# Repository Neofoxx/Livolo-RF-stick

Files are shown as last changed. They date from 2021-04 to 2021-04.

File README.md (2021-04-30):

# LIVOLO-RF-Stick
A USB dongle for controlling Livolo RF switches

#### Finished product
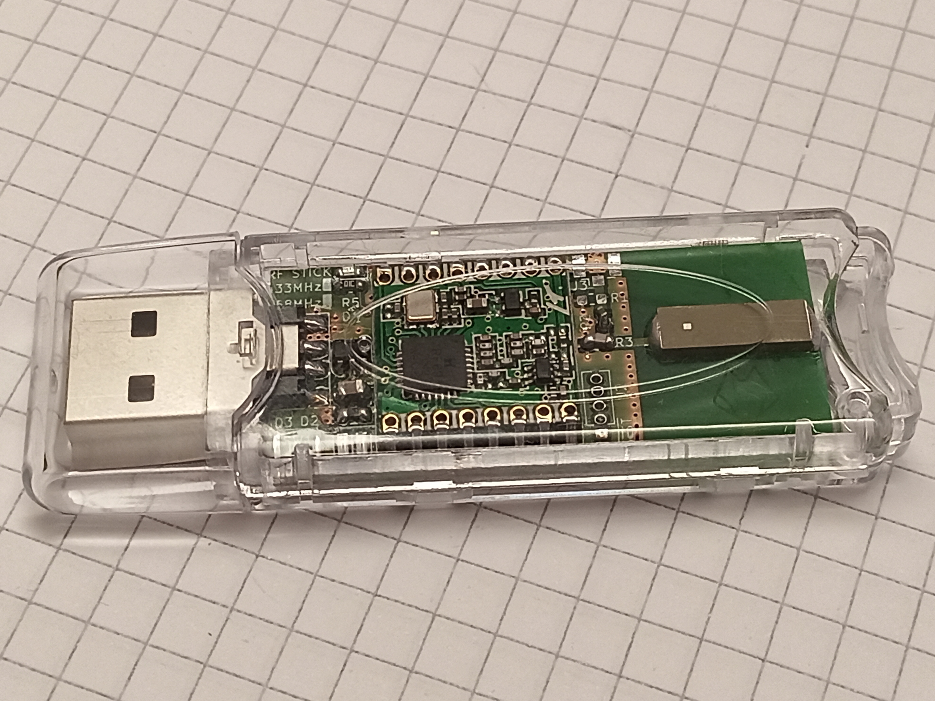
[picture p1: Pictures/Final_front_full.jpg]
Front view of finished product

*Front view of finished product*

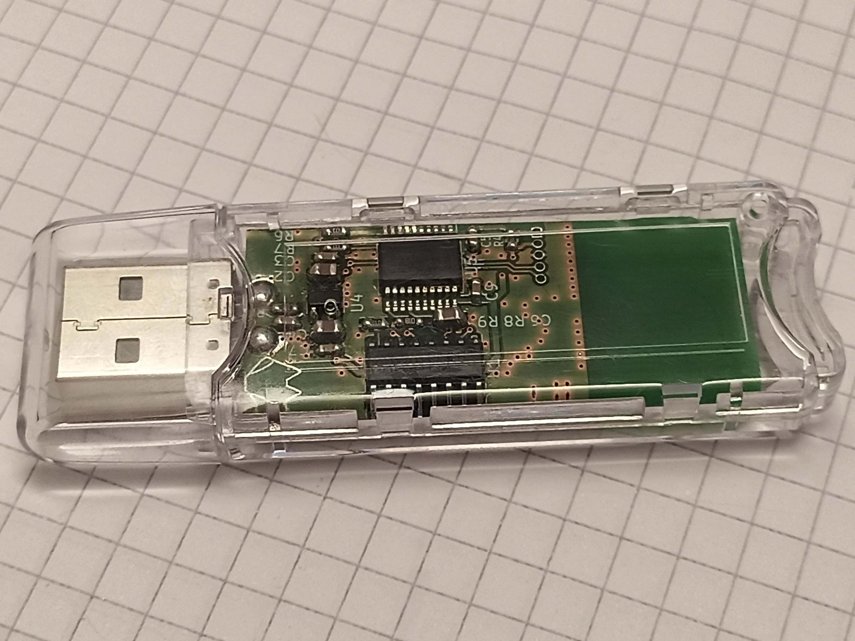
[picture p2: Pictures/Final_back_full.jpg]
Back view of finished product

*Back view of finished product*

#### PCB board view
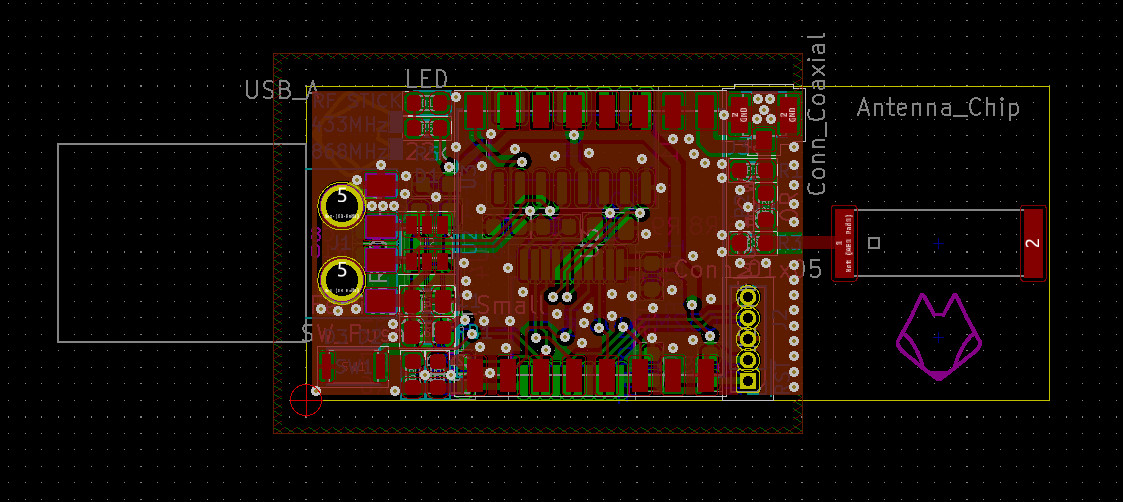
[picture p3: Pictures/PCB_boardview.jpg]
PCB board view

*PCB board view*

## Description

This is a simple dongle for controling Livolo brand RF switched.
It is based around the following components:
- [PIC32MM0064GPL020s](https://www.microchip.com/wwwproducts/en/PIC32MM0064GPL020) microcontroller
- [RFM69](https://www.hoperf.com/modules/rf_transceiver/RFM69HCW.html) module
- CH340G USB-serial converter
- ABRACON [ACAG1204-433-T](https://abracon.com/datasheets/ACAG1204-433-T.pdf) ceramic antenna
- Multicomp [MCG1901](https://uk.farnell.com/multicomp/mcg1901/box-usb-plug-in-clear-polycarbonate/dp/1603603) plastic housing (Wifi dongle style)

#### Performance
Performance is about on-par with the official handheld remote.
Antenna tuning is 72nH in series with antenna, 1pF in parallel with antenna.

#### Extra info

A longer writeup can be found [here](https://neofoxx.com/post-4.html).

## Usage example

Connect to the dongle at 115200bps, 8N1.
Send commands like "COMMAND [...]\n". Commands can be either lower or uppercase.

A help command is implemented, and will printout this:
```
RF stick, for controlling Livolo switches␊
Commands:␊
HELP - Print this help
SCAN - Perform an RSSI scan of a wider area
DEBUG - Print out some diagnostic data
SNIFF [Minimum RSSI] [Timeout] - Sniff for Livolo packets.
-> RSSI should be [-115 to 0]. In practice, use -80, maybe -90 for really weak signals
-> Timeout is in miliseconds. You can put 0 for no timeout. You can always end by sending \n
TRANSMIT [Remote ID] [Keycode] [Number of repeats] - Send a packet many times
-> Remote ID is a 16-bit unsigned number
-> Keycode is a 6-bit unsigned number
-> Number of packets can be [1 to 1000]. Each one takes 8ms, fyi.
----> THIS DOES NOT VERIFY IF YOU DATA IS CORRECT. YOU HAVE TO MAKE SURE THAT YOU HAVE THE RIGHT NUMBER OF 1s!
```

Take special care when sending packets, as the switches are fussy about how many you send -> they **react differently** to how many packets you send.
- ON/OFF commands - 25 to 30 packets is kinda the ideal. If you send more than 50, weird things start happening (lights turning ON and then back OFF or vice versa)
- DIMMING commands - a minimum of 20 packets works reliably. It sometimes works with less, but it's not recommended. This means you can dim the light on in increments, by sending >=20 packets for each UP increment.

Each button on a remote send two different key codes, depending on how you press a button.
- SHORT press - send those 25-30 packets, with a keycode **X**
- LONG press - continues sending packets until release, with keycode **Y**. Used for dimming

To synchronize/bind a key, you **MUST** send the **ON/OFF** command (**SHORT press**). After you put the switch into its "synchronize/learning/binding" mode of course. The switch should respond with a single **beep** when button is bound (at least on my test switch)-

To unbind a key, you *can* send the the **ON/OFF** sequence twice (or just a longer packet), when the switch is in its "synchronize/learning/binding" mode. The switch should responded with two **beeps** when it unbinds (again, works on my test unit).
This also works with a normal remote, if you double-tap a key, though I couldn't find this functionality in the included mini-manual.

#### TLDR
1. Send "SNIFF -90 20", so get the REMOTE_ID and Keycode_ID from your existing remote
2. Send "TRANSMIT [REMOTE_ID] [Keycode_ID] 25" for ON/OFF commands
3. Send "TRANSMIT [REMOTE_ID] [Keycode_ID] [DO_YOUR_OWN_MATH]" for dimming commands. Time sending packets = (8ms * number_of_packets), or flipped, number_of_packets = total_time_in_ms / 8.

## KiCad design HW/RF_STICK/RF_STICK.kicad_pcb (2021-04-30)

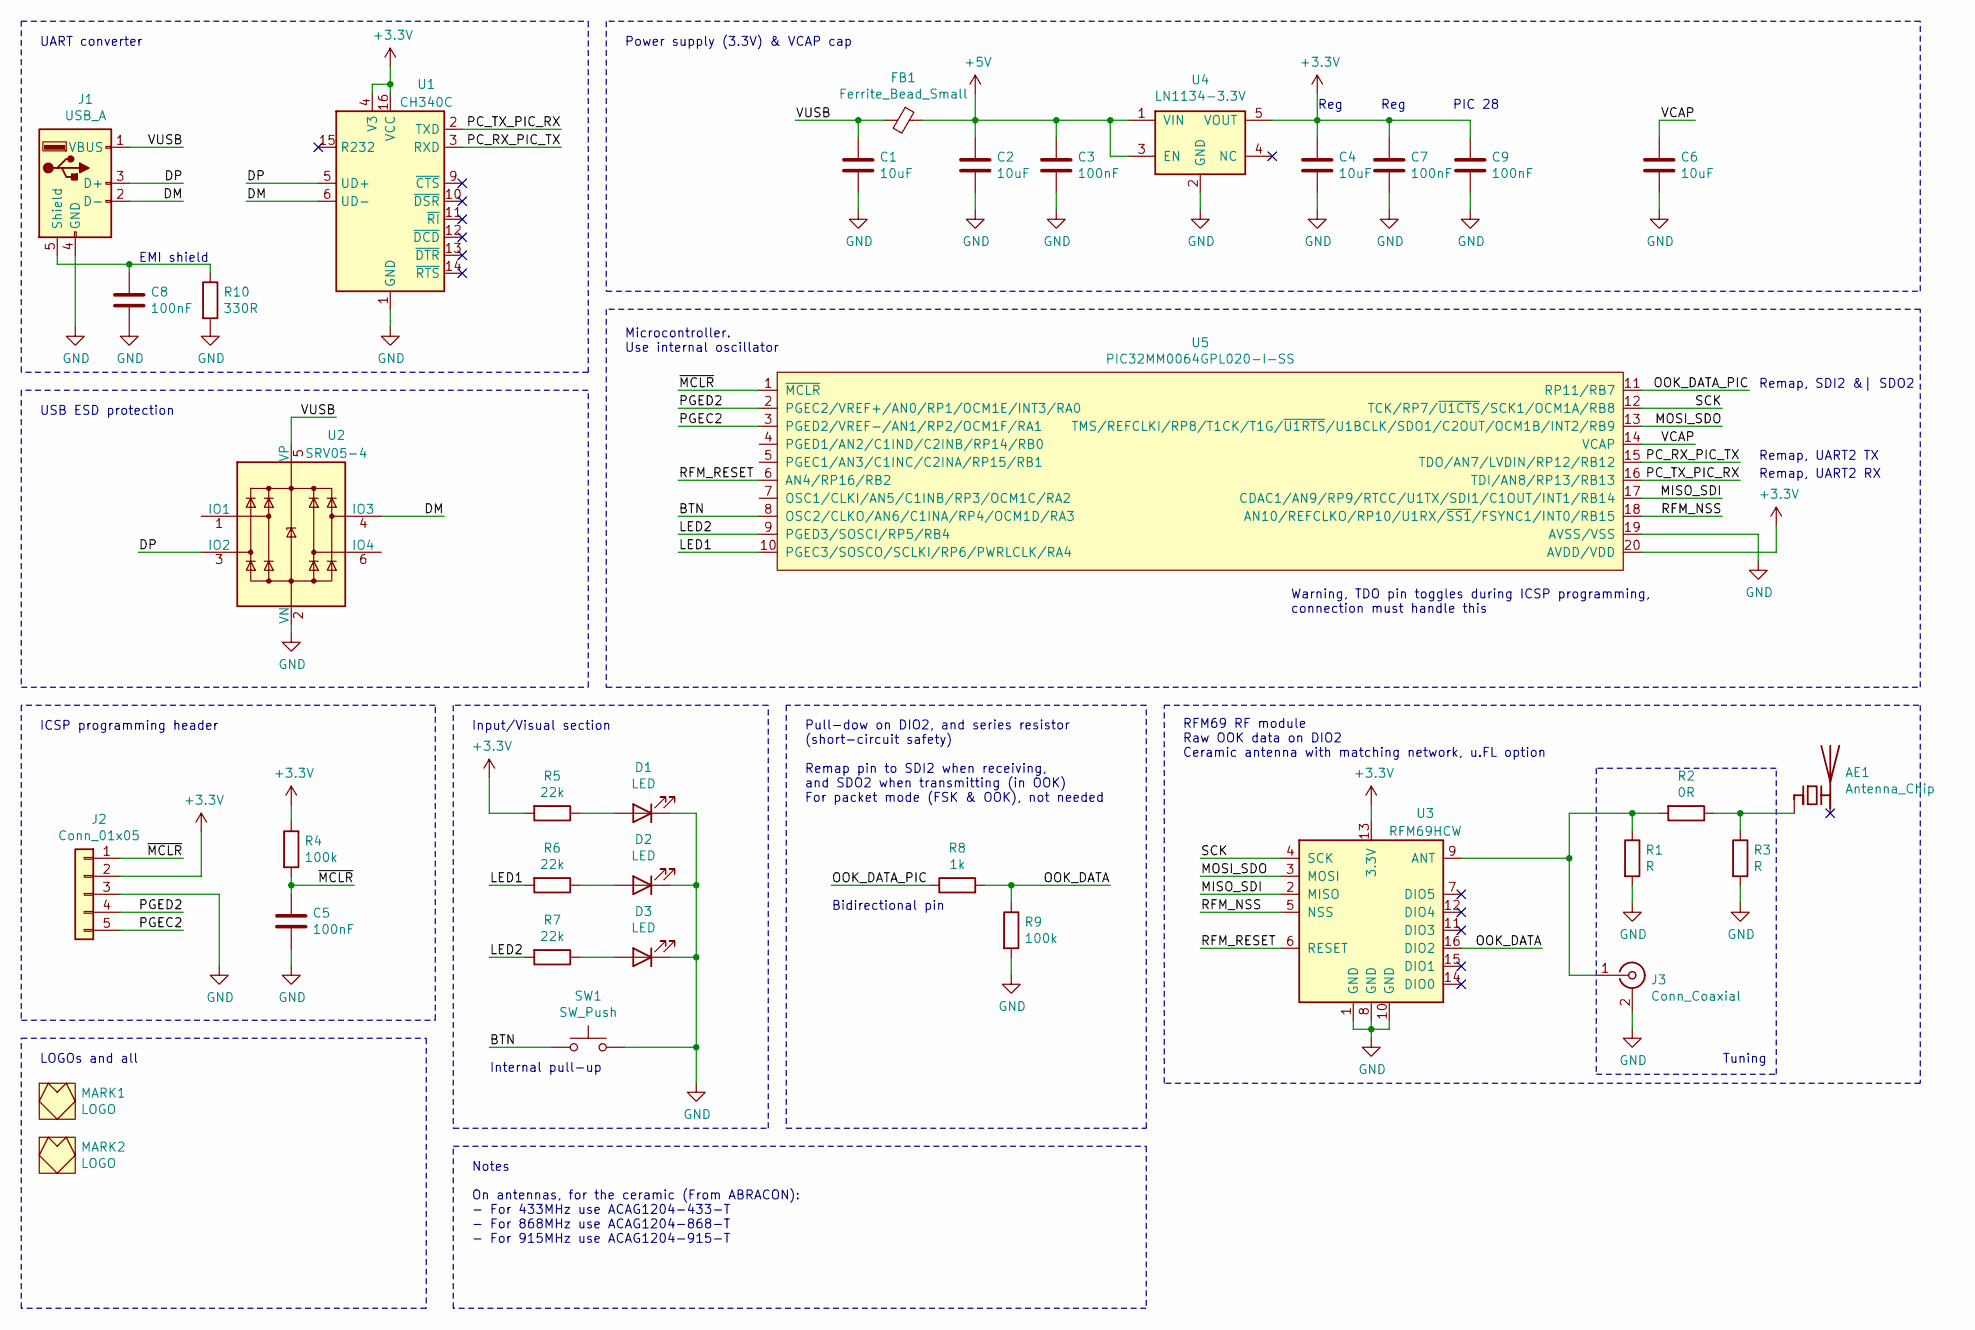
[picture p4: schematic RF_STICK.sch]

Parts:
AE1: Antenna_Chip; ACAG1204-433-T
C1, C2, C4, C6: 10uF; C_0805_2012Metric
C3, C5, C7, C8, C9: 100nF; C_0603_1608Metric
D1, D2, D3: LED; LED_0603_1608Metric
FB1: Ferrite_Bead_Small; L_0805_2012Metric
J1: USB_A; USB_A_PCB
J2: Conn_01x05; PinHeader_1x05_P1.27mm_Vertical
J3: Conn_Coaxial; U.FL_Hirose_U.FL-R-SMT-1_Vertical
MARK1, MARK2: LOGO; FOX_LOGO_MASK
R1, R3: R; R_0603_1608Metric
R2: 0R; R_0603_1608Metric
R4, R9: 100k; R_0603_1608Metric
R5, R6, R7: 22k; R_0603_1608Metric
R8: 1k; R_0603_1608Metric
R10: 330R; R_0603_1608Metric
SW1: SW_Push; SW_SPST_CK_KXT3
U1: CH340C; SOIC-16_3.9x9.9mm_P1.27mm
U2: SRV05-4; SOT-23-6
U3: RFM69HCW; HOPERF_RFM9XW_SMD
U4: LN1134-3.3V; SOT-23-5
U5: PIC32MM0064GPL020-I-SS; SSOP-20_5.3x7.2mm_P0.65mm_MOD

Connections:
+3V3: C4.1, C7.1, C9.1, J2.2, R4.1, R5.2, U1.4 (V3), U1.16 (VCC), U3.13 (3.3V), U4.5 (VOUT), U5.20 (AVDD/VDD)
+5V: C2.1, C3.1, FB1.1, U4.1 (VIN), U4.3 (EN)
/BTN: SW1.1, U5.8 (OSC2/CLKO/AN6/C1INA/RP4/OCM1D/RA3)
/DM: J1.2 (D-), U1.6 (UD-), U2.4 (IO3)
/DP: J1.3 (D+), U1.5 (UD+), U2.3 (IO2)
/LED1: R6.2, U5.10 (PGEC3/SOSCO/SCLKI/RP6/PWRLCLK/RA4)
/LED2: R7.2, U5.9 (PGED3/SOSCI/RP5/RB4)
/MISO_SDI: U3.2 (MISO), U5.17 (CDAC1/AN9/RP9/RTCC/U1TX/SDI1/C1OUT/INT1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)
/MOSI_SDO: U3.3 (MOSI), U5.13 (TMS/REFCLKI/RP8/T1CK/T1G/~U1RTS~/U1BCLK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)
/OOK_DATA: R8.2, R9.1, U3.16 (DIO2)
/OOK_DATA_PIC: R8.1, U5.11 (RP11/RB7)
/PC_RX_PIC_TX: U1.3 (RXD), U5.15 (TDO/AN7/LVDIN/RP12/RB12)
/PC_TX_PIC_RX: U1.2 (TXD), U5.16 (TDI/AN8/RP13/RB13)
/PGEC2: J2.5, U5.3 (PGED2/VREF-/AN1/RP2/OCM1F/RA1)
/PGED2: J2.4, U5.2 (PGEC2/VREF+/AN0/RP1/OCM1E/INT3/RA0)
/RFM_NSS: U3.5 (NSS), U5.18 (AN10/REFCLKO/RP10/U1RX/~SS1~/FSYNC1/INT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)
/RFM_RESET: U3.6 (RESET), U5.6 (AN4/RP16/RB2)
/SCK: U3.4 (SCK), U5.12 (TCK/RP7/~U1CTS~/SCK1/OCM1A/RB8)
/VCAP: C6.1, U5.14 (VCAP)
/VUSB: C1.1, FB1.2, J1.1 (VBUS), U2.5 (VP)
/~MCLR~: C5.1, J2.1, R4.2, U5.1 (~MCLR~)
GND: C1.2, C2.2, C3.2, C4.2, C5.2, C6.2, C7.2, C8.2, C9.2, D1.1 (K), D2.1 (K), D3.1 (K), J1.4 (GND), J2.3, J3.2 (Ext), R1.2, R3.2, R9.2, R10.2, SW1.2, U1.1 (GND), U2.2 (VN), U3.1 (GND), U3.8 (GND), U3.10 (GND), U4.2 (GND), U5.19 (AVSS/VSS)
unnamed: AE1.1 (FEED), R2.1, R3.1
unnamed: C8.1, J1.5 (Shield), R10.1
unnamed: D1.2 (A), R5.1
unnamed: D2.2 (A), R6.1
unnamed: D3.2 (A), R7.1
unnamed: J3.1 (In), R1.1, R2.2, U3.9 (ANT)

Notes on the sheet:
Reg
PIC 28
Remap, UART2 TX
Remap, SDI2 &| SDO2
Remap, UART2 RX
UART converter
USB ESD protection
Microcontroller. Use internal oscillator
Power supply (3.3V) & VCAP cap
Bidirectional pin
Internal pull-up
ICSP programming header
Input/Visual section
Tuning
RFM69 RF module Raw OOK data on DIO2 Ceramic antenna with matching network, u.FL option
Pull-dow on DIO2, and series resistor (short-circuit safety) Remap pin to SDI2 when receiving, and SDO2 when transmitting (in OOK) For packet mode (FSK & OOK), not needed
LOGOs and all
Notes
On antennas, for the ceramic (From ABRACON): - For 433MHz use ACAG1204-433-T - For 868MHz use ACAG1204-868-T - For 915MHz use ACAG1204-915-T
Warning, TDO pin toggles during ICSP programming, connection must handle this
EMI shield

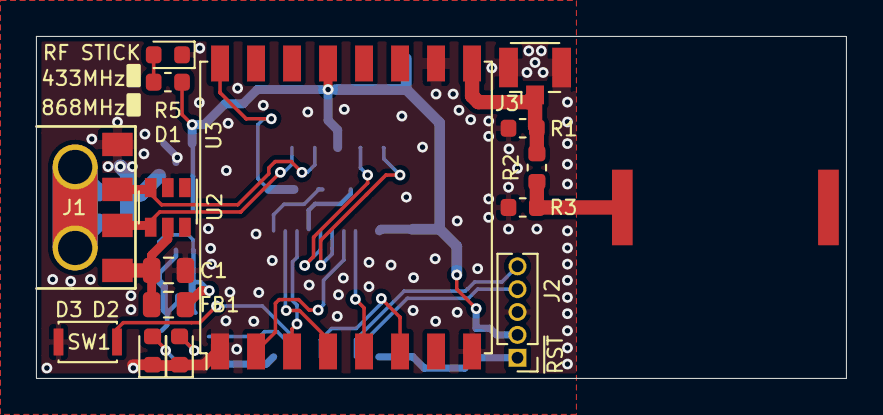
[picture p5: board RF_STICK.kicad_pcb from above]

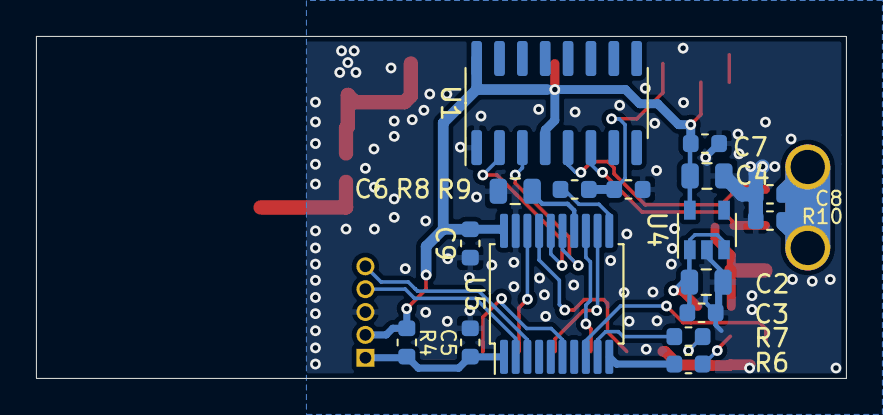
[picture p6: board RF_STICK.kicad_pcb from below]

Board: 2 copper layers, 45.0 x 19.0 mm, 35 parts (18 on the bottom side), 28 nets.

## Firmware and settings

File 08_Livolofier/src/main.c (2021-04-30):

#include <p32xxxx.h>    // Always in first place to avoid conflict with const.h -> this includes xc.h
#include <const.h>      // MIPS32
#include <inttypes.h>
#include <string.h>
#include <stdio.h>
#include <newlib.h>
#include <errno.h>
#include <stdbool.h>

// Drivers for HW
#include <configBits.h>
#include <GPIODrv.h>
#include <UARTDrv.h>
#include <SPIDrv.h>
#include <BTN.h>
#include <LED.h>
#include <COMMS.h>
#include <helper.h>
#include <RFM69.h>


// These numbers are for a baud of 57142bps.
#define LIVOLO_PREAMBLE_LEN_MIN	(32-2)
#define LIVOLO_PREAMBLE_LEN_MAX	(32+2)
#define LIVOLO_ONE_LEN_MIN	(19-2)
#define LIVOLO_ONE_LEN_MAX	(19+2)
#define LIVOLO_ZERO_LEN_MIN	(9-2)
#define LIVOLO_ZERO_LEN_MAX	(9+2)


char tempArray[512];
uint32_t lengthArray = 0;


void simpleDelay(unsigned int noOfLoops){
    unsigned int i = 0;
    while (i<noOfLoops){
        i++;
        asm("nop");
    }
}

void MIPS32 INTEnableSystemMultiVectoredInt(void)
{
    uint32_t val;

    // set the CP0 cause IV bit high
    asm volatile("mfc0   %0,$13" : "=r"(val));
    val |= 0x00800000;
    asm volatile("mtc0   %0,$13" : "+r"(val));

    INTCONSET = _INTCON_MVEC_MASK;

    // set the CP0 status IE bit high to turn on interrupts
    //INTEnableInterrupts();
	asm("ei");
}


void setup(){

	


	SYSKEY = 0x00000000;      // force lock
	SYSKEY = 0xAA996655;      // unlock
	SYSKEY = 0x556699AA; 

	SPLLCON = (0b000 << 24)	// PLLODIV = PLL divide-by-1, so we get 24MHZ from 24MHz
		| (0b0000001 << 16)		// PLLMULT = x3, so 8MHz * 3 = 24MHz
		| (0b1 << 7);			// FRC is selected as input to PLL


//	SPLLCON = (0b010 << 24)	// PLLODIV = PLL divide-by-4, so we get 24MHZ from 96MHz
//	| (0b0000101 << 16)		// PLLMULT = x12, so 8MHz * 12 = 96MHz
//	| (0b1 << 7);			// FRC is selected as input to PLL


	simpleDelay(1000);


	OSCCONbits.NOSC = 1;	// Switch to SPLL
	
	OSCCONSET = 1;			// Sets the OSWEN bit, that forces a change to news settings in NOSC
	
	SYSKEY = 0x00000000;      // force lock

	simpleDelay(100000);

	
	LED_init();
	BTN_init();
	UARTDrv_Init(115200);
	
	
	
	SPIDrv_Init(1000000, 1, 0, 0, SPI_MODE_NORMAL);	// 1MHz, CKE = 1, CKP = 0, SMP = 0, normal SPI mode.
	RFM69_Init();
	
	
	// Enable interrupts
//	INTEnableSystemMultiVectoredInt();
	
	//	_CP0_BIS_CAUSE(_CP0_CAUSE_IV_MASK);

	// Enable multi-vectored mode


	// set the CP0 status IE bit high to turn on interrupts
	//INTEnableInterrupts();
	//asm("ei");	// Compiler handles this, but should be same as _CP0_BIS_STATUS(_CP0_STATUS_IE_MASK)

	// As per datasheet
	unsigned int temp_CP0;
	asm volatile("di"); 
	asm volatile("ehb");
	temp_CP0 = _CP0_GET_CAUSE();
	temp_CP0 |= 0x00800000;
	_CP0_SET_CAUSE(temp_CP0);
	INTCONSET = _INTCON_MVEC_MASK;
	
	asm volatile("ei"); 
}

void rssiSniffer(){
	// Try to roll through frequencies, get RSSI.
	uint32_t startFreq = 430000000;
	uint32_t stopFreq = 435000000;
	uint32_t step = 10000;
	int16_t rssiCurr = -128;
	int16_t rssiTemp = -128;
	uint32_t counter = 0;
	uint32_t numCounts = 10;

	int16_t maxRSSI = -128;
	int32_t maxFreq = 0;
	
	LED_setGreen(1);

	for (; startFreq <= stopFreq; startFreq = startFreq + step){
		rssiCurr = -128;
		rssiTemp = -128;
		RFM69_SetRfCarrierFreq(startFreq);
		for (counter = 0; counter < numCounts; counter++){
			rssiTemp = RFM69_GetRSSI();
			if (rssiTemp > rssiCurr){
				rssiCurr = rssiTemp;
			}
		}
		
		if (rssiCurr > maxRSSI){
			maxRSSI = rssiCurr;
			maxFreq = startFreq;
		}
		
		lengthArray = sprintf(tempArray, "RSSI @ %ldkHz is %ddBm\n", startFreq/1000, rssiCurr);
		UARTDrv_SendBlocking((uint8_t *) tempArray, lengthArray);    
		
				
	}

	lengthArray = sprintf(tempArray, "Peak RSSI was %ddBm @ %ldkHz\n", maxRSSI, maxFreq/1000);
	UARTDrv_SendBlocking((uint8_t *) tempArray, lengthArray);   
	
	LED_setGreen(0);


	RFM69_Init();	// Need to set back to proper frequency, and this is the quickest.
}

void tryCapture(int16_t time, int16_t minRssi){

	uint32_t toRun = true;

	uint32_t startTime = _CP0_GET_COUNT();
	uint32_t totalCount = (((uint64_t)FCLK/(uint64_t)2) * (uint64_t)time) / 1000;	

	LED_setGreen(1);

	lengthArray = sprintf(tempArray, "Packet Capture procedure. Waiting for RSSI >= %ddBm\n", minRssi);
	UARTDrv_SendBlocking((uint8_t *) tempArray, lengthArray);

	// Perform for x seconds
	while(toRun){

		int16_t tempRssi = RFM69_GetRSSI();

		if (tempRssi >= minRssi){
			lengthArray = sprintf(tempArray, "RSSI is good (%ddBm), proceeding\n", tempRssi);
			UARTDrv_SendBlocking((uint8_t *) tempArray, lengthArray);	
			
			SPIDrv_Init(57142, 1, 0, 0, SPI_MODE_RX_OTHER_SDI);
			
			// One packet is 8ms, or 57B. Double to be sure to get something, +%
			uint8_t suggestiveData[128] = {0};
			SPIDrv_SendReceiveBlocking(suggestiveData, suggestiveData, 128);
			
			/*
			uint32_t counter = 0;
			int8_t bitCounter = 0;
			lengthArray = 0;
			for (counter = 0; counter<128; counter++){
				for (bitCounter = 7; bitCounter>0; bitCounter--){
					lengthArray = lengthArray + sprintf(&tempArray[lengthArray], "%d", (suggestiveData[counter] & (1<<bitCounter)) ? 1 : 0);
				}
				//lengthArray = lengthArray + sprintf(&tempArray[lengthArray], "%02x", suggestiveData[counter]);
				lengthArray = lengthArray + sprintf(&tempArray[lengthArray], ",");
			}
			lengthArray = lengthArray + sprintf(&tempArray[lengthArray], "\nDONE\n");
			UARTDrv_SendBlocking((uint8_t *) tempArray, lengthArray);
			*/
			
			// Procedure, find needs in haystack (preamble)
			// Then decode 24bits (varying width), probably a 0 at the end but we'll see
			
			// Get next pattern - startPosition BYTE, startPosition BIT, stopPosition BYTE.
			// Should return (bitVal, numOfBits, and end).
			
			uint32_t bitPos = 1;
			uint32_t bitPosLimit = sizeof(suggestiveData) * 8;
			
			uint32_t done = 0;
			
			// Data should be MSB FIRST!
			
			uint8_t prevBit = (suggestiveData[0] >> 7) & 0x01;
			uint32_t currBitCounter = 1;
			
			bool preambleFound = false;
			uint32_t data = 0;
			uint8_t dataCounter = 0;
			uint8_t shortCounter = 0;
			
			while (!done && bitPos<bitPosLimit){
				uint32_t whichByte = bitPos >> 3;			// 3 bits from 0-7 are bit pos, other are bytes.
				uint32_t whichBit = 7 - (bitPos & 0b111);	// Bit pos
				uint8_t currBit = (suggestiveData[whichByte] >> whichBit) & 0x01;	
				
				if (currBit == prevBit){
					currBitCounter++;
					
					// Should check if we're checking the last bit (dataCounter == 22)
					// .....
				}
				else{
					//lengthArray = sprintf(tempArray, "Bit val %d, length %d\n", prevBit, currBitCounter);
    				//UARTDrv_SendBlocking((uint8_t *) tempArray, lengthArray);
    				
    				// Discern here
    				
					if (currBitCounter >= LIVOLO_PREAMBLE_LEN_MIN && currBitCounter <= LIVOLO_PREAMBLE_LEN_MAX){
						preambleFound = true;
						data = 0;
						dataCounter = 0;
					}
    					
					else if (preambleFound == true){
						// If one
						
						if (currBitCounter >= LIVOLO_ONE_LEN_MIN && currBitCounter <= LIVOLO_ONE_LEN_MAX){
							data = (data << 1) | 1;
							shortCounter = 0;
							dataCounter++;
						}
						else if (currBitCounter >= LIVOLO_ZERO_LEN_MIN && currBitCounter <= LIVOLO_ZERO_LEN_MAX){
							shortCounter++;
							if (shortCounter == 2){
								shortCounter = 0;
								data = (data << 1);
								dataCounter++;
							}
						}
						else if (dataCounter == 22){
							// When _we_ transmit, the last bit can be a bit longer...
							// We can asume that it is a 0, if shortCounter == 1, else assume 1
							if (shortCounter == 1){
								shortCounter = 0;
								data = (data << 1);
								dataCounter++;
							}
							else{
								data = (data << 1) | 1;
								shortCounter = 0;
								dataCounter++;
							}
						}
						else{
							// Invalid data.
							preambleFound = false;
							data = 0;
							dataCounter = 0;
						}
						
    				}
    				
    				else{
    					// Not valid bit.
    					preambleFound = false;
						data = 0;
						dataCounter = 0;
    				}
    				
    				if (dataCounter == 23){
    					done = true;
    				}
    				
    				prevBit = currBit;
    				currBitCounter = 1;
				}
			
				bitPos++;
			}

			if (done){			
				uint16_t remote = (data >> 7) & 0xFFFF;
				uint8_t keycode = data & 0x7F;
				//lengthArray = sprintf(tempArray, "Bit val %d, length %d\n", prevBit, currBitCounter);
				lengthArray = sprintf(tempArray, "RemoteID %d, KeycodeID %d\n", remote, keycode);
				UARTDrv_SendBlocking((uint8_t *) tempArray, lengthArray);
			}
			else{
				lengthArray = sprintf(tempArray, "No luck\n");
				UARTDrv_SendBlocking((uint8_t *) tempArray, lengthArray);
			}
			
			SPIDrv_Init(1000000, 1, 0, 0, SPI_MODE_NORMAL);		// Revert back to normal
		}
	
	
	
		// Check exit conditions
		// Either timeout (when > 0), or any new character in buffer (non-exclusive)
		if (time > 0){
			if ((_CP0_GET_COUNT() - startTime) >= totalCount){
				toRun = 0;
			}
		}
		
		if (COMMS_helper_dataLen(&comStruct_UART_RX)){
			toRun = 0;
		}
	
	}
	
	LED_setGreen(0);
	
	lengthArray = sprintf(tempArray, "Read end\n");
	UARTDrv_SendBlocking((uint8_t *) tempArray, lengthArray);
	
}

void sendPacket(uint16_t id, uint8_t keycode, uint16_t numTimes){
	// Prepare SPI out buffer first
	uint8_t outData[64];
	uint8_t lenData = 0;
	uint8_t bitPos = 7;
	
	memset(outData, 0, sizeof(outData));
		
	// Preamble is a LONG pulse.
	// Subsequent pulses are two short pulses for 0, or 1 long pulse for 1.

	uint32_t counter = 0;
	uint32_t counterInner = 0;
	uint32_t nextVal = 0;
	
	LED_setRed(1);
	
	for (counter = 0; counter < (LIVOLO_PREAMBLE_LEN_MIN + LIVOLO_PREAMBLE_LEN_MAX) / 2; counter++){
		outData[lenData] = outData[lenData] | (1<<bitPos);
		bitPos--;
		if (bitPos > 7){
			lenData++;
			bitPos = 7;
		}
	}
	
	for (counter = 0; counter < 16; counter++){
		if (id & (1<<(15-counter))){
			for (counterInner = 0; counterInner < (LIVOLO_ONE_LEN_MIN + LIVOLO_ONE_LEN_MAX) / 2; counterInner++){
				outData[lenData] = outData[lenData] | (nextVal<<bitPos);
				bitPos--;
				if (bitPos > 7){
					lenData++;
					bitPos = 7;
				}
			}
			
			nextVal = (nextVal + 1) & 0x01;
					
		}
		else{
			for (counterInner = 0; counterInner < (LIVOLO_ZERO_LEN_MIN + LIVOLO_ZERO_LEN_MAX) / 2; counterInner++){
				outData[lenData] = outData[lenData] | (nextVal<<bitPos);
				bitPos--;
				if (bitPos > 7){
					lenData++;
					bitPos = 7;
				}
			}
			
			nextVal = (nextVal + 1) & 0x01;
			
			for (counterInner = 0; counterInner < (LIVOLO_ZERO_LEN_MIN + LIVOLO_ZERO_LEN_MAX) / 2; counterInner++){
				outData[lenData] = outData[lenData] | (nextVal<<bitPos);
				bitPos--;
				if (bitPos > 7){
					lenData++;
					bitPos = 7;
				}
			}	
			
			nextVal = (nextVal + 1) & 0x01;
		}
	}
	
	for (counter = 0; counter < 7; counter++){
		if (keycode & (1<<(6-counter))){
			for (counterInner = 0; counterInner < (LIVOLO_ONE_LEN_MIN + LIVOLO_ONE_LEN_MAX) / 2; counterInner++){
				outData[lenData] = outData[lenData] | (nextVal<<bitPos);
				bitPos--;
				if (bitPos > 7){
					lenData++;
					bitPos = 7;
				}
			}
			
			nextVal = (nextVal + 1) & 0x01;
					
		}
		else{
			for (counterInner = 0; counterInner < (LIVOLO_ZERO_LEN_MIN + LIVOLO_ZERO_LEN_MAX) / 2; counterInner++){
				outData[lenData] = outData[lenData] | (nextVal<<bitPos);
				bitPos--;
				if (bitPos > 7){
					lenData++;
					bitPos = 7;
				}
			}
			
			nextVal = (nextVal + 1) & 0x01;
			
			for (counterInner = 0; counterInner < (LIVOLO_ZERO_LEN_MIN + LIVOLO_ZERO_LEN_MAX) / 2; counterInner++){
				outData[lenData] = outData[lenData] | (nextVal<<bitPos);
				bitPos--;
				if (bitPos > 7){
					lenData++;
					bitPos = 7;
				}
			}	
			
			nextVal = (nextVal + 1) & 0x01;
		}
	}
	
	// The data HAS to end on a 0.
	
	// Should there be an extra 1 at the end, to give the decoder an edge to latch on to? (all pun intended)
	// Maybe, need to check if a Livolo devices accepts it or not
	// -> If it doesn't then the SPI thing won't be completely OK for this,
	// -> and a simple "if timer overflown then set bit = x" will be better...
	// We could also... copy the last sent byte to the _end_ of the array. And rotate. Coyote laying the tracks style
	// 'cos you gotta know, the original remote is fucky. Sometimes it drops a bit at the end, so I suspect fimilar fuckery.
	
	// So, turns out, that the Livolo switches __really__ need that next edge to latch on to.
	// Without it (say another zero half period), it doesn't budge. So no period, or prolonged last bit == no bueno.
	// This sucks. It also means we'll have to use a more simple TX-ing mechanism with timed delays.
	
/*	
	// Done.
	
	
	lengthArray = sprintf(tempArray, "Wrote to outData: %d %d\n", lenData, bitPos);
	UARTDrv_SendBlocking((uint8_t *) tempArray, lengthArray);
	
	for (counter = 0; counter < (lenData+1); counter++){
		lengthArray = sprintf(tempArray, "0x%X ", outData[counter]);
		UARTDrv_SendBlocking((uint8_t *) tempArray, lengthArray);
	}
	lengthArray = sprintf(tempArray, "\n");
	UARTDrv_SendBlocking((uint8_t *) tempArray, lengthArray);


	// Config RFM for TXing
	uint8_t temp = RFM69_ReadReg(RFM69_RegOpMode);
	RFM69_SetReg(RFM69_RegOpMode, ((0b011 << RFM69_RegOpMode_Bit_Shift_Mode) & RFM69_RegOpMode_Bit_Mask_Mode) );		// Switch to TX mode, automatically.
	
	while(!(RFM69_ReadReg(RFM69_RegIrqFlags1) & RFM69_RegIrqFlags1_Bit_Mask_ModeReady)){
	}
	
	SPIDrv_Init(57142, 1, 0, 0, SPI_MODE_TX_OTHER_SDO);
	

	// We will write 1B more - it's just 0s anyway
	for (counter = 0; counter < numTimes; counter++){		
		SPIDrv_SendBlocking(outData, lenData + 1);
	}


	SPIDrv_Init(1000000, 1, 0, 0, SPI_MODE_NORMAL);		// Revert back to normal
	RFM69_SetReg(RFM69_RegOpMode, temp);
	while(!(RFM69_ReadReg(RFM69_RegIrqFlags1) & RFM69_RegIrqFlags1_Bit_Mask_ModeReady)){
	}
	
*/	

	uint32_t combinedData = (uint32_t)(keycode & 0x7F) | (((uint32_t)(id)) << 7);
	
	uint32_t startTime;
	uint32_t uSecondTicks = ((uint64_t)FCLK/(uint64_t)2) / 1000000;
	uint32_t countPreamble = uSecondTicks * 560;	// Preamble is a nominal 560us high
	uint32_t countHigh = uSecondTicks * 325;	// High is a nominal 325us high (could also be 315us, or 330us)
	uint32_t countLow = uSecondTicks * 157;		// Low is a nominal 2 * 157us low
	nextVal = 0;
		

	uint8_t temp = RFM69_ReadReg(RFM69_RegOpMode);
	RFM69_SetReg(RFM69_RegOpMode, ((0b011 << RFM69_RegOpMode_Bit_Shift_Mode) & RFM69_RegOpMode_Bit_Mask_Mode) );		// Switch to TX mode, automatically.
	
	while(!(RFM69_ReadReg(RFM69_RegIrqFlags1) & RFM69_RegIrqFlags1_Bit_Mask_ModeReady)){
	}
	
	GPIODrv_initSpecialPin(GPIO_MODE_OUTPUT);
	
	// TX here	
	for (counter = 0; counter < numTimes; counter++){
		// Set pin
		GPIODrv_setSpecialPin(true);	
		// Wait
		startTime = _CP0_GET_COUNT();
		while ((_CP0_GET_COUNT() - startTime) < countPreamble){
		}
		
		nextVal = 0;
	
		for (counterInner = 0; counterInner < 23; counterInner++){
			if (combinedData & (1<<(22-counterInner))){
				// Set pin
				GPIODrv_setSpecialPin(nextVal);
				
				nextVal = (nextVal + 1) & 0x01;
				// Wait
				startTime = _CP0_GET_COUNT();
				while ((_CP0_GET_COUNT() - startTime) < countHigh){
				}
			}
			else{
				// Set pin
				GPIODrv_setSpecialPin(nextVal);
				
				nextVal = (nextVal + 1) & 0x01;
				
				startTime = _CP0_GET_COUNT();
				while ((_CP0_GET_COUNT() - startTime) < countLow){
				}
				
				// Set pin
				GPIODrv_setSpecialPin(nextVal);
				
				nextVal = (nextVal + 1) & 0x01;
				
				startTime = _CP0_GET_COUNT();
				while ((_CP0_GET_COUNT() - startTime) < countLow){
				}
			}		
		}
	
	}
	
	GPIODrv_initSpecialPin(GPIO_MODE_INPUT);
	
	RFM69_SetReg(RFM69_RegOpMode, temp);
	while(!(RFM69_ReadReg(RFM69_RegIrqFlags1) & RFM69_RegIrqFlags1_Bit_Mask_ModeReady)){
	}
	
	LED_setRed(0);

}

void toUpper(char *buf, uint32_t len){
	uint32_t counter = 0;
	for (counter = 0; counter < len; counter++){
		if (buf[counter] >= 97 && buf[counter] <= 122){
			buf[counter] = buf[counter] - 32;
		}
	}
}
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
int main(){

	//bool printout = true;
	uint32_t lenPos = 0;
	char myBuffer[cyclicBufferSize];
	
	char command[17];
	int32_t operands[4];

	setup();


    for(;;){
/*    
    	lengthArray = sprintf(tempArray, "Looping %ld\n", COMMS_helper_dataLen(&comStruct_UART_RX));
    	UARTDrv_SendBlocking((uint8_t *) tempArray, lengthArray);
   
   		lengthArray = sprintf(tempArray, "Vals 0x%08X 0x%08X 0x%08X 0x%08X\n", IFS1, IEC1, IPC10, INTCON);
    	UARTDrv_SendBlocking((uint8_t *) tempArray, lengthArray);
*/    
    
    
    	// Find out, if we need to go:
    	// - TX /w param (remoteId, keyCode, numTransmits)
    	// - RX /w param (time?, rssi?)
    	
    	if (COMMS_helper_charPresent(&comStruct_UART_RX, '\n', &lenPos)){
    		COMMS_helper_getData(&comStruct_UART_RX, (uint8_t *)myBuffer, lenPos);
    	}
    	else if (!COMMS_helper_spaceLeft(&comStruct_UART_RX)){
    		// STOP SPAMMING
    		COMMS_helper_dropAll(&comStruct_UART_RX);
    		continue;
    	}
    	else{
    		continue;
    	}
    	
    	toUpper(myBuffer, lenPos);
    	
    	sscanf(myBuffer, "%16s", command);
    	
    	if (0 == strcmp(command, "SNIFF")){
    		sscanf(myBuffer, "%16s %ld %ld", command, &operands[0], &operands[1]);
    		if (operands[0] < -115 || operands[0] > 0			// Min RSSI
    			|| operands[1] < 0 || operands[1] > 15000){		// time to sniff. 0 == forever
    			// Bork & return
    			continue;
    		}
    		
    		tryCapture(operands[1], operands[0]);
    	}
    	
    	else if (0 == strcmp(command, "TRANSMIT")){
    		// Minimum number of transmits for "on/off" should be ~30. Use 50. Don't use more than 100, or it'll turn itself off :D
    		// For "dim up", 20 seems to be a minimum. There is a limit to the discretization the switch does
    		
    		// For pairing, use 30. More than that and it'll unpair itself :p
    		// -> While the manual doesn't says this, on the remote, if you start synchronization (one "Dit"),
    		// -> Then press a buttons (second "Dit"), this synchronizes/binds the button the the dwitch
    		// -> If you press a button _again_ (THIRD "Dit"), it will unpair/unbind it!
    		// -> Hende why a 50 here will cause trouble. Fun tho, and you don't have to unlearn everything.
    	
    		sscanf(myBuffer, "%16s %ld %ld %ld", command, &operands[0], &operands[1], &operands[2]);
    		if (operands[0] < 0 || operands[0] >= 65535			// Remote id is 16-bit
    			|| operands[1] < 0 || operands[1] >= 127		// Keycode is 7-bit
    			|| operands[2] < 0 || operands[2] >= 1001){		// 1000 repeats is 8 seconds
    			// Bork & return
    			continue;
    		}
    		
    		sendPacket(operands[0], operands[1], operands[2]);
    	}   
    	
    	else if (0 == strcmp(command, "DEBUG")){
    		printDebug();
    	}
    	
    	else if (0 == strcmp(command, "SCAN")){
    		rssiSniffer();	// Fixed frequencies is fine for now.
    	}
    	
    	else if (0 == strcmp(command, "HELP")){
    		lengthArray = sprintf(tempArray, "RF stick, for controlling Livolo switches\n");
			UARTDrv_SendBlocking((uint8_t *) tempArray, lengthArray);
			
			lengthArray = sprintf(tempArray, "Commands:\n");
			UARTDrv_SendBlocking((uint8_t *) tempArray, lengthArray);
			
			lengthArray = sprintf(tempArray, "HELP - Print this help\n");
			UARTDrv_SendBlocking((uint8_t *) tempArray, lengthArray);
			
			lengthArray = sprintf(tempArray, "SCAN - Perform an RSSI scan of a wider area\n");
			UARTDrv_SendBlocking((uint8_t *) tempArray, lengthArray);
			
			lengthArray = sprintf(tempArray, "DEBUG - Print out some diagnostic data\n");
			UARTDrv_SendBlocking((uint8_t *) tempArray, lengthArray);
			
			lengthArray = sprintf(tempArray, "SNIFF [Minimum RSSI] [Timeout] - Sniff for Livolo packets.\n");
			UARTDrv_SendBlocking((uint8_t *) tempArray, lengthArray);
			lengthArray = sprintf(tempArray, "-> RSSI should be [-115 to 0]. In practice, use -80, maybe -90 for really weak signals\n");
			UARTDrv_SendBlocking((uint8_t *) tempArray, lengthArray);
			lengthArray = sprintf(tempArray, "-> Timeout is in miliseconds. You can put 0 for no timeout. You can always end by sending \\n\n");
			UARTDrv_SendBlocking((uint8_t *) tempArray, lengthArray);
			
			lengthArray = sprintf(tempArray, "TRANSMIT [Remote ID] [Keycode] [Number of repeats] - Send a packet many times\n");
			UARTDrv_SendBlocking((uint8_t *) tempArray, lengthArray);
			lengthArray = sprintf(tempArray, "-> Remote ID is a 16-bit unsigned number\n");
			UARTDrv_SendBlocking((uint8_t *) tempArray, lengthArray);
			lengthArray = sprintf(tempArray, "-> Keycode is a 6-bit unsigned number\n");
			UARTDrv_SendBlocking((uint8_t *) tempArray, lengthArray);
			lengthArray = sprintf(tempArray, "-> Number of packets can be [1 to 1000]. Each one takes 8ms, fyi.\n");
			UARTDrv_SendBlocking((uint8_t *) tempArray, lengthArray);
			lengthArray = sprintf(tempArray, "----> THIS DOES NOT VERIFY IF YOU DATA IS CORRECT. YOU HAVE TO MAKE SURE THAT YOU HAVE THE RIGHT NUMBER OF 1s!\n");
			UARTDrv_SendBlocking((uint8_t *) tempArray, lengthArray);
			
			
    	}
    	    

/*    
    	lengthArray = sprintf(tempArray, "Waiting %d 0x%X 0x%X\n", BTN_getStatus(), PORTA, CNPUA);
		UARTDrv_SendBlocking((uint8_t *) tempArray, lengthArray);
		LED_setRed(1);



    	if (BTN_getStatus()){
    		printout = !printout;
    	}

	
    	if(printout){
    		LED_setGreen(1);
    		uint8_t temp;
   				
    	}
    	else{
    		LED_setGreen(0);
    		
    		sendPacket(25984, 68<<1, 100);
    	}
    	
    	delayms(250);
    	delayms(250);
    	delayms(250);
    	
*/    	    	
    }

/**********************************************************************/

    return(0);
    
} // end of main

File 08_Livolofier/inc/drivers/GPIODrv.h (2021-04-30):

#ifndef GPIODRV_H_573f2ca8b43e44209acc90f0f9b7de5d
#define GPIODRV_H_573f2ca8b43e44209acc90f0f9b7de5d

#include <inttypes.h>
#include <stdbool.h>

#define GPIO_MODE_OUTPUT 	0
#define GPIO_MODE_INPUT 	1
#define GPIO_MODE_HIZ 		2



// LED - RED
#define LEDRED_TRISbits		TRISBbits
#define LEDRED_TRISPIN		TRISB4
#define LEDRED_LATbits		LATBbits
#define LEDRED_LATPIN		LATB4
#define LEDRED_LATINV		LATBINV
#define LEDRED_MASK			(1<<4)

// LED - GREEN
#define LEDGREEN_TRISbits	TRISAbits
#define LEDGREEN_TRISPIN	TRISA4
#define LEDGREEN_LATbits	LATAbits
#define LEDGREEN_LATPIN		LATA4
#define LEDGREEN_LATINV		LATAINV
#define LEDGREEN_MASK		(1<<4)



// Button
#define BTN_TRISbits		TRISAbits
#define BTN_TRISPIN			TRISA3
#define BTN_PORTbits		PORTAbits
#define BTN_PORTPIN			RA3
#define BTN_PULLREG			CNPUA	// Call also pull down with CNPDx
#define BTN_PULLBIT			(1<<3)
#define BTN_ANSELbits		ANSELAbits
#define BTN_ANSELPIN		ANSA3



// UART - UART2, need to remap
#define UART_TX_TRISbits		TRISBbits
#define UART_TX_TRISPIN			TRISB12
#define UART_TX_LATbits			LATBbits
#define UART_TX_LATPIN			LATB12
#define UART_TX_REMAP_BITS		RPOR2bits
#define UART_TX_REMAP_SUB		RP12R
#define UART_TX_REMAP_VAL		1	// Remap U2TX to that pin
#define UART_TX_ANSELbits		ANSELBbits
#define UART_TX_ANSELPIN		ANSB12

#define UART_RX_TRISbits		TRISBbits
#define UART_RX_TRISPIN			TRISB13
#define UART_RX_PULLREG			CNPUB	// UARTs are idle high, so pull-up
#define UART_RX_PULLBIT			(1<<13)
#define UART_RX_REMAP_BITS		RPINR9bits
#define UART_RX_REMAP_SUB		U2RXR
#define UART_RX_REMAP_VAL		13	// Remap pin 13 to UART2 RX
#define UART_RX_ANSELbits		ANSELBbits
#define UART_RX_ANSELPIN		ANSB13



#define UART_MODE_bits		U2MODEbits
#define UART_STA_bits		U2STAbits
#define UART_BRG_reg		U2BRG
#define UART_TX_reg			U2TXREG
#define UART_RX_reg			U2RXREG




// SPI - SPI2
// SDI - MISO
#define SPI_SDI_TRISbits		TRISBbits
#define SPI_SDI_TRISPIN			TRISB14
#define SPI_SDI_PULLREG			CNPDB	// Prevent floating pins, pull-up or pull-down is OK.
#define SPI_SDI_REMAP_BITS		RPINR11bits
#define SPI_SDI_REMAP_SUB		SDI2R
#define SPI_SDI_REMAP_VAL		9	// Remap RB14, RP9 onto SDI
#define SPI_SDI_MASK			(1<<14)
#define SPI_SDI_ANSELbits		ANSELBbits
#define SPI_SDI_ANSELPIN		ANSB14

// SDO - MOSI
#define SPI_SDO_TRISbits		TRISBbits
#define SPI_SDO_TRISPIN			TRISB9
#define SPI_SDO_REMAP_BITS		RPOR1bits
#define SPI_SDO_REMAP_SUB		RP8R	// RB9, RP8
#define SPI_SDO_REMAP_VAL		3	// Remap SDO2 to that pin

// SCK
#define SPI_SCK_TRISbits		TRISBbits
#define SPI_SCK_TRISPIN			TRISB8
#define SPI_SCK_LATbits			LATBbits
#define SPI_SCK_LATPIN			LATB8
#define SPI_SCK_LATSET			LATBSET
#define SPI_SCK_LATCLR			LATBCLR
#define SPI_SCK_MASK			(1<<8)
#define SPI_SCK_REMAP_BITS		RPOR1bits
#define SPI_SCK_REMAP_SUB		RP7R
#define SPI_SCK_REMAP_VAL		4	// Remap SCK2 to that pin

// NSS - RFM69, active LOW, SW controlled
#define SPI_NSS_TRISbits		TRISBbits
#define SPI_NSS_TRISPIN			TRISB15
#define SPI_NSS_LATbits			LATBbits
#define SPI_NSS_LATPIN			LATB15
#define SPI_NSS_LATSET			LATBSET
#define SPI_NSS_LATCLR			LATBCLR
#define SPI_NSS_MASK			(1<<15)
#define SPI_NSS_ANSELbits		ANSELBbits
#define SPI_NSS_ANSELPIN		ANSB15

// DIO2 SDI&SDO dual-action pin
#define SPI_DIO2_TRISbits			TRISBbits
#define SPI_DIO2_TRISPIN			TRISB7
#define SPI_DIO2_LATbits			LATBbits
#define SPI_DIO2_LATPIN				LATB7
#define SPI_DIO2_DI_REMAP_BITS		RPINR11bits
#define SPI_DIO2_DI_REMAP_SUB		SDI2R
#define SPI_DIO2_DI_REMAP_VAL		11	// Remap RP11 onto SDI
#define SPI_DIO2_DO_REMAP_BITS		RPOR2bits
#define SPI_DIO2_DO_REMAP_SUB		RP11R
#define SPI_DIO2_DO_REMAP_VAL		3	// Remap SDO2 to that pin



// RFM69
// RESET - active high
#define RFM_RESET_TRISbits		TRISBbits
#define RFM_RESET_TRISPIN		TRISB2
#define RFM_RESET_LATbits		LATBbits
#define RFM_RESET_LATPIN		LATB2
#define RFM_RESET_LATSET		LATBSET
#define RFM_RESET_LATCLR		LATBCLR
#define RFM_RESET_MASK			(1<<2)
#define RFM_RESET_ANSELbits		ANSELBbits
#define RFM_RESET_ANSELPIN		ANSB2

void GPIODrv_initSpecialPin(uint32_t mode);
void GPIODrv_setSpecialPin(bool state);

#endif

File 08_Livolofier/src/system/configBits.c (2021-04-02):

#include <p32xxxx.h>
#include <inttypes.h>
#include <configBits.h>

/*
// Configuration bits for the PIC32MM0256GPM064 or 036? chip. PRIMARY configuration
const uint32_t __attribute__((section (".SECTION_FDEVOPT"))) temp_fdevopt = 
	0x00003FE7
	| ((0xF0C5) << _FDEVOPT_USERID_POSITION)	// UserID is F0C5. NOTE! for some reason, it's declared as _17_ bits wide in the .h file. 		
												// Hence this hack, to have it aligned, since the definition shifts by 15, instead of 16...
	| (0b0 << _FDEVOPT_FVBUSIO_POSITION)	// VBUSON pin is controlled by port function, not USB
	| (0b0 << _FDEVOPT_FUSBIDIO_POSITION)	// USBID pin is controlled by port function, not USB	
	| (0b1 << _FDEVOPT_ALTI2C_POSITION)	// SDA1 and SCL1 are on pins RB8 and RB9											
	| (0b1 << _FDEVOPT_SOSCHP_POSITION);	// SOSC operated in Normal Power mode

const uint32_t __attribute__((section (".SECTION_FICD"))) temp_ficd =
	0xFFFFFFE3
	| (0b10 << _FICD_ICS_POSITION)			// Communication is on PGEC2/PGED2
	| (0b1 << _FICD_JTAGEN_POSITION);		// JTAG is enabled

const uint32_t __attribute__((section (".SECTION_FPOR"))) temp_fpor =
	0xFFFFFFF0
	| (0b0 << _FPOR_LPBOREN_POSITION)		// Low-Power BOR is disabled
	| (0b0 << _FPOR_RETVR_POSITION)			// Retention regulator is enabled, controlled by RETEN in sleep
	| (0b00 << _FPOR_BOREN_POSITION);		// Brown-out reset disabled in HW, SBOREN bit disabled

const uint32_t __attribute__((section (".SECTION_FWDT"))) temp_fwdt =
	0xFFFF0000
	| (0b0 << _FWDT_FWDTEN_POSITION)		// Watchdog Timer disabled
	| (0b00 << _FWDT_RCLKSEL_POSITION)		// Clock source is system clock
	| (0b10000 << _FWDT_RWDTPS_POSITION)	// Run mode Watchdog Postscale is 1:65536
	| (0b1 << _FWDT_WINDIS_POSITION)		// Windowed mode is disabled
	| (0b00 << _FWDT_FWDTWINSZ_POSITION)	// Watchdog Timer window size is 75%
	| (0b10000 << _FWDT_SWDTPS_POSITION);	// Sleep mode Watchdog Postscale is 1:65536 

const uint32_t __attribute__((section (".SECTION_FOSCSEL"))) temp_foscsel =
	0xFFFF2828
	| (0b01 << _FOSCSEL_FCKSM_POSITION)		// Clock switching ENABLED, Fail-Safe clock monitor disabled
	| (0b1 << _FOSCSEL_SOSCSEL_POSITION)	// Crystal is used for SOSC, RA4/RB4 controlled by SOSC
	| (0b1 << _FOSCSEL_OSCIOFNC_POSITION)	// System clock not on CLKO pin, operates as normal I/O
	| (0b11 << _FOSCSEL_POSCMOD_POSITION)	// Primary oscillator is disabled
	| (0b0 << _FOSCSEL_IESO_POSITION)		// Two-speed Start-up is disabled
	| (0b0 << _FOSCSEL_SOSCEN_POSITION)		// Secondary oscillator disabled
	| (0b1 << _FOSCSEL_PLLSRC_POSITION)		// FRC is input to PLL on device Reset
	| (0b000 << _FOSCSEL_FNOSC_POSITION);	// Oscillator is FRC with "Divide-by-N". We will switch to PLL later.

const uint32_t __attribute__((section (".SECTION_FSEC"))) temp_fsec =
	0x7FFFFFFF
	| (0b1 << _FSEC_CP_POSITION);			// Code protection disabled
// End PRIMARY configuration

// Configuration bits for the PIC32MM chip. ALTERNATE configuration
const uint32_t __attribute__((section (".SECTION_AFDEVOPT"))) temp_afdevopt = 
	0x0000FFF7
	| ((0xF0C5) << _FDEVOPT_USERID_POSITION)	// UserID is F0C5. NOTE! for some reason, it's declared as _17_ bits wide in the .h file. 
												// Hence this hack, to have it aligned, since the definition shifts by 15, instead of 16...
	| (0b1 << _FDEVOPT_SOSCHP_POSITION);	// SOSC operated in Normal Power mode

const uint32_t __attribute__((section (".SECTION_AFICD"))) temp_aficd =
	0xFFFFFFE3
	| (0b01 << _FICD_ICS_POSITION)			// Communication is on PGEC3/PGED3
	| (0b1 << _FICD_JTAGEN_POSITION);		// JTAG is enabled

const uint32_t __attribute__((section (".SECTION_AFPOR"))) temp_afpor =
	0xFFFFFFF0
	| (0b0 << _FPOR_LPBOREN_POSITION)		// Low-Power BOR is disabled
	| (0b0 << _FPOR_RETVR_POSITION)			// Retention regulator is enabled, controlled by RETEN in sleep
	| (0b00 << _FPOR_BOREN_POSITION);		// Brown-out reset disabled in HW, SBOREN bit disabled

const uint32_t __attribute__((section (".SECTION_AFWDT"))) temp_afwdt =
	0xFFFF0000
	| (0b0 << _FWDT_FWDTEN_POSITION)		// Watchdog Timer disabled
	| (0b00 << _FWDT_RCLKSEL_POSITION)		// Clock source is system clock
	| (0b10000 << _FWDT_RWDTPS_POSITION)	// Run mode Watchdog Postscale is 1:65536
	| (0b1 << _FWDT_WINDIS_POSITION)		// Windowed mode is disabled
	| (0b00 << _FWDT_FWDTWINSZ_POSITION)	// Watchdog Timer window size is 75%
	| (0b10000 << _FWDT_SWDTPS_POSITION);	// Sleep mode Watchdog Postscale is 1:65536 

const uint32_t __attribute__((section (".SECTION_AFOSCSEL"))) temp_afoscsel =
	0xFFFF2828
	| (0b01 << _FOSCSEL_FCKSM_POSITION)		// Clock switching ENABLED, Fail-Safe clock monitor disabled
	| (0b1 << _FOSCSEL_SOSCSEL_POSITION)	// Crystal is used for SOSC, RA4/RB4 controlled by SOSC
	| (0b1 << _FOSCSEL_OSCIOFNC_POSITION)	// System clock not on CLKO pin, operates as normal I/O
	| (0b11 << _FOSCSEL_POSCMOD_POSITION)	// Primary oscillator is disabled
	| (0b0 << _FOSCSEL_IESO_POSITION)		// Two-speed Start-up is disabled
	| (0b0 << _FOSCSEL_SOSCEN_POSITION)		// Secondary oscillator disabled
	| (0b1 << _FOSCSEL_PLLSRC_POSITION)		// FRC is input to PLL on device Reset
	| (0b001 << _FOSCSEL_FNOSC_POSITION);	// Oscillator is FRC with "Divide-by-N". We will switch to PLL later.

const uint32_t __attribute__((section (".SECTION_AFSEC"))) temp_afsec =
	0x7FFFFFFF
	| (0b1 << _FSEC_CP_POSITION);			// Code protection disabled
// End ALTERNATE configuration
*/

// Configuration bits for the PIC32MM0064GPL038 chip. PRIMARY configuration
const uint32_t __attribute__((section (".SECTION_FDEVOPT"))) temp_fdevopt = 
	0x0000FFF7
	| ((0x8383 << 1) << _FDEVOPT_USERID_POSITION)	// UserID. Same <<1 thing as for some other devices...	
	| (0b1 << _FDEVOPT_SOSCHP_POSITION);		// SOSC operated in Normal Power mode

const uint32_t __attribute__((section (".SECTION_FICD"))) temp_ficd =
	0xFFFFFFE3
	| (0b10 << _FICD_ICS_POSITION)			// Communication is on PGEC2/PGED2
	| (0b0 << _FICD_JTAGEN_POSITION);		// JTAG is DISABLED

const uint32_t __attribute__((section (".SECTION_FPOR"))) temp_fpor =
	0xFFFFFFF0
	| (0b0 << _FPOR_LPBOREN_POSITION)		// Low-Power BOR is disabled
	| (0b0 << _FPOR_RETVR_POSITION)			// Retention regulator is enabled, controlled by RETEN in sleep
	| (0b00 << _FPOR_BOREN_POSITION);		// Brown-out reset disabled in HW, SBOREN bit disabled
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

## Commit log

2021-03-27 First commit, just for backup
    [RF_STICK-B_Cu.gbl, RF_STICK-B_Mask.gbs, RF_STICK-B_SilkS.gbo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]
2021-04-02 Mid-work commit. Interrupts work, command parsing works, etc
2021-04-30 Working version
    [RF_STICK.kicad_pcb]
